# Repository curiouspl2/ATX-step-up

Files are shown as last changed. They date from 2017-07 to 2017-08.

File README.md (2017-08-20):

# ATX-step-up
DC DC step up driver turning flaky and sagging ATX power supply to stable 14V or 24V source

One can also use it to 'parallel' power supplies - just connect each power supply to separate input. 

v3 version supports four inputs, rated 10-20A each (depends on heatsinking and mosfets used).

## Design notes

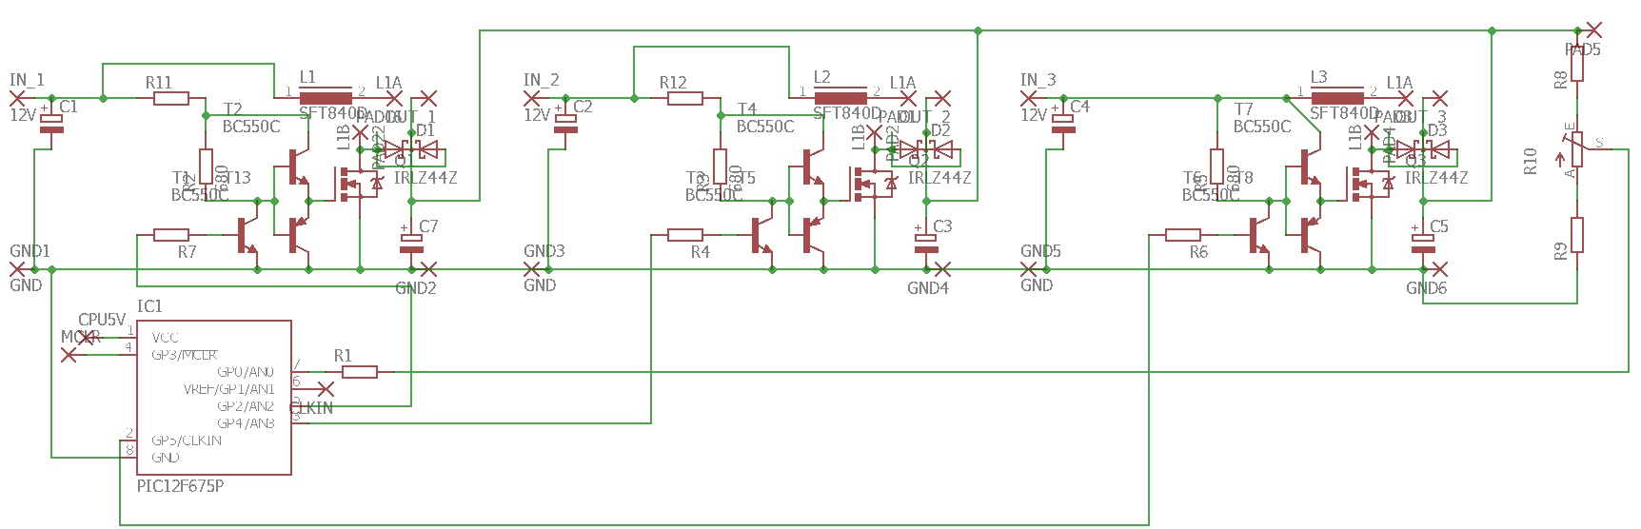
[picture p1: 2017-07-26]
pic_single_module_v1.png

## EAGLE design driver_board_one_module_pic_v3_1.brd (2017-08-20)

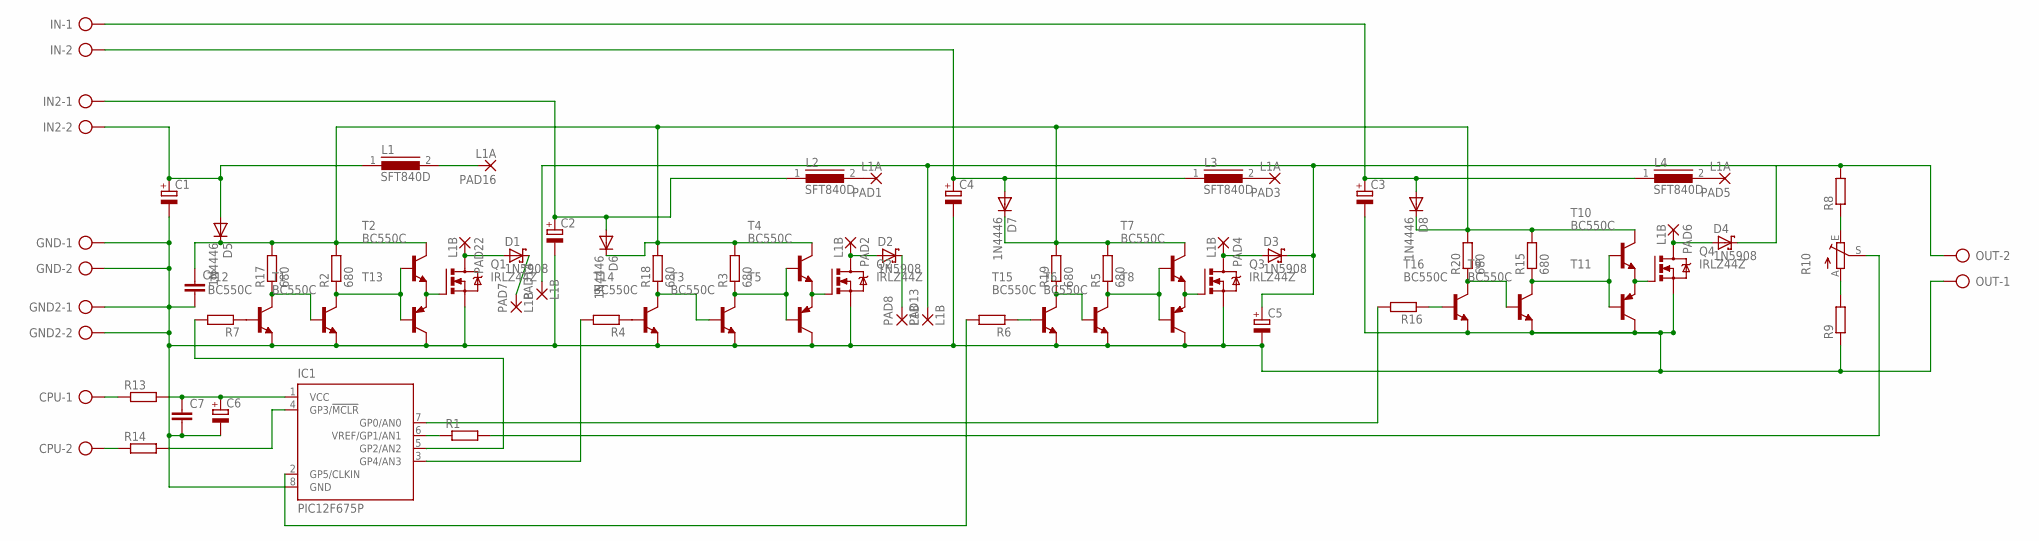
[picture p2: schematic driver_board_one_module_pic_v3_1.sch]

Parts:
C1, C2, C3, C4, C5, C6: CPOL-EUE5-8.5; E5-8,5
C7: C-EUC1206K; C1206K
C8: C-EU050-045X075; C050-045X075
CPU: AK300/2
D1, D2, D3, D4: 1N5908; C4111-15
D5, D6, D7, D8: 1N4446; DO35-10
GND, GND2: AK300/2
IC1: PIC12F675P; DIL8
IN, IN2: AK300/2
L1, L2, L3, L4: SFT840D
OUT: AK300/2
PAD1, PAD3, PAD5, PAD16: L1A; 3,81/1,1
PAD2, PAD4, PAD6, PAD7, PAD8, PAD13, PAD14, PAD22: L1B; 3,81/1,1
Q1, Q2, Q3, Q4: IRLZ44Z; TO220BH
R1, R8, R9, R13, R14: R-EU_0204/5; 0204/5
R2: 680; 0207/7
R3, R5, R15, R17, R18, R19, R20: 680; 0204/5
R4: R-EU_0207/7; 0207/7
R6, R7: R-EU_0207/12; 0207/12
R10: TRIM_EU-RJ9W; RJ9W
R16: R-EU_0207/10; 0207/10
T1, T2, T3, T4, T6, T7, T9, T10, T12, T14, T15, T16: BC550C; TO92-EBC
T5, T8, T11, T13: BC557C-PNP-TO92-EBC; TO92-EBC

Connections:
GND: C1.-, C2.-, C3.-, C4.-, C5.-, C6.-, C7.2, C8.2, GND.1, GND.2, GND2.1, GND2.2, IC1.8 (GND), OUT.1, Q1.S, Q2.S, Q3.S, Q4.S, R9.1, T1.E, T3.E, T5.C, T6.E, T8.C, T9.E, T11.C, T12.E, T13.C, T14.E, T15.E, T16.E
unnamed: Q1.G, T2.E, T13.E
unnamed: IC1.7 (GP0/AN0), R16.2
unnamed: Q2.G, T4.E, T5.E
unnamed: CPU.1, R13.1
unnamed: R9.2, R10.A
unnamed: R6.1, T15.B
unnamed: CPU.2, R14.1
unnamed: D2.A, PAD2.1, Q2.D
unnamed: R8.1, R10.E
unnamed: L2.2, PAD1.1
unnamed: Q3.G, T7.E, T8.E
unnamed: Q4.G, T10.E, T11.E
unnamed: R7.1, T12.B
unnamed: R1.2, R10.S
unnamed: R17.1, T1.B, T12.C
unnamed: D3.A, PAD4.1, Q3.D
unnamed: R4.1, T14.B
unnamed: R18.1, T3.B, T14.C
unnamed: L3.2, PAD3.1
unnamed: IC1.5 (GP2/AN2), R7.2
unnamed: IC1.3 (GP4/AN3), R4.2
unnamed: IC1.2 (GP5/CLKIN), R6.2
unnamed: C6.+, C7.1, IC1.1 (VCC), R13.2
unnamed: IC1.4 (GP3/!MCLR), R14.2
unnamed: IC1.6 (VREF/GP1/AN1), R1.1
unnamed: C1.+, D5.A, IN2.2, L1.1
unnamed: C2.+, D6.A, IN2.1, L2.1
unnamed: C4.+, D7.A, IN.2, L3.1
unnamed: D1.C, PAD7.1
unnamed: R16.1, T16.B
unnamed: L1.2, PAD16.1
unnamed: D1.A, PAD22.1, Q1.D
unnamed: R2.1, T1.C, T2.B, T13.B
unnamed: D4.A, PAD6.1, Q4.D
unnamed: L4.2, PAD5.1
unnamed: R3.1, T3.C, T4.B, T5.B
unnamed: C3.+, D8.A, IN.1, L4.1
unnamed: R5.1, T6.C, T7.B, T8.B
unnamed: R15.1, T9.C, T10.B, T11.B
unnamed: R19.1, T6.B, T15.C
unnamed: R20.1, T9.B, T16.C
unnamed: D2.C, PAD8.1
unnamed: C8.1, D5.C, D6.C, D7.C, D8.C, R2.2, R3.2, R5.2, R15.2, R17.2, R18.2, R19.2, R20.2, T2.C, T4.C, T7.C, T10.C
unnamed: C5.+, D3.C, D4.C, OUT.2, PAD13.1, PAD14.1, R8.2

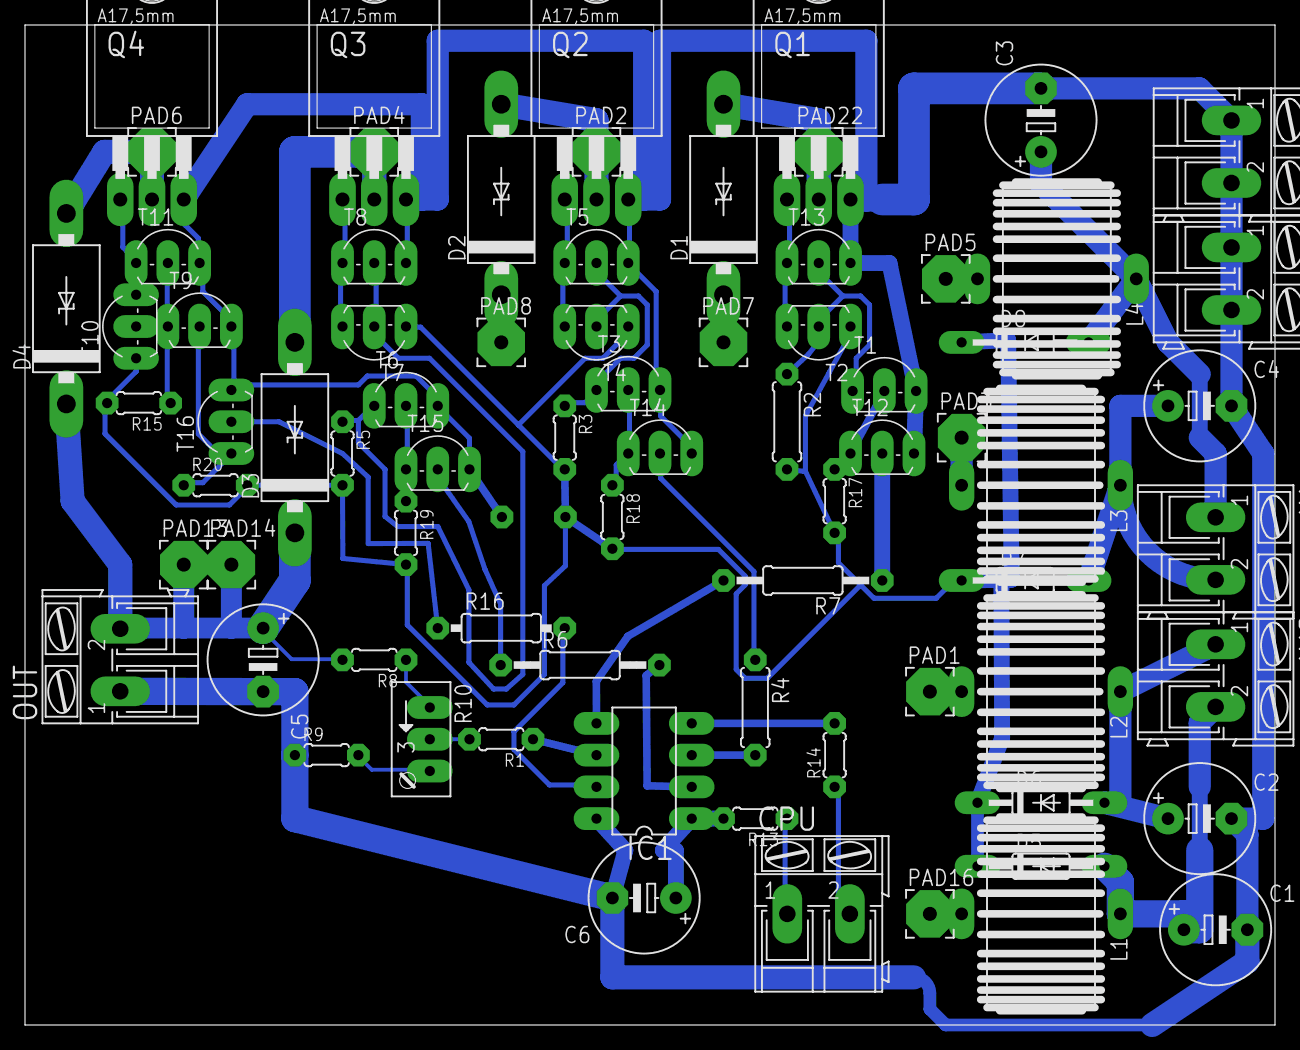
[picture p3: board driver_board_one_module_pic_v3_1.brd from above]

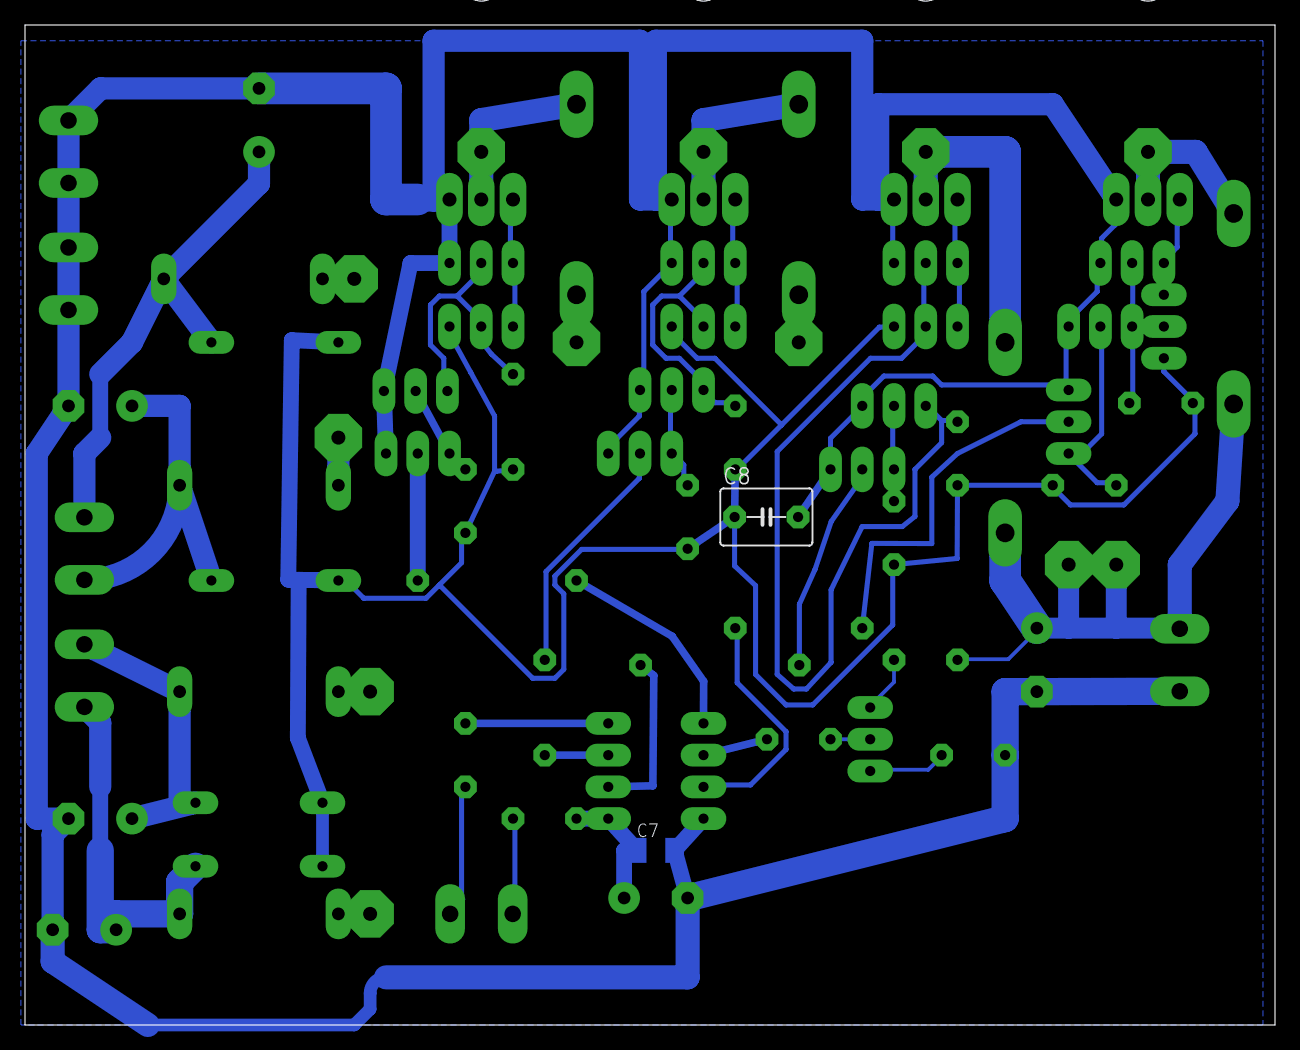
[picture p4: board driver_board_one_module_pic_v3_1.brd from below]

Board: 2 copper layers, 100.0 x 80.0 mm, 77 parts (2 on the bottom side), 45 nets.

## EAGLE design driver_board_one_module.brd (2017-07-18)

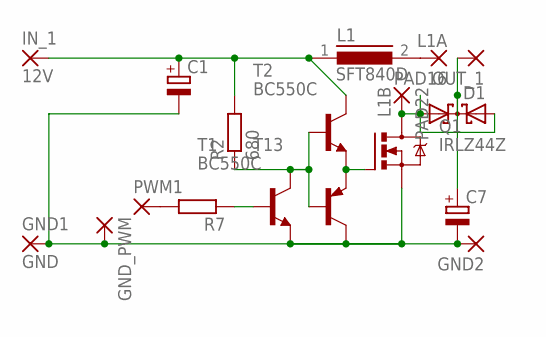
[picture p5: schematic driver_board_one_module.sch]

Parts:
C1, C7: CPOL-EUE5-8.5; E5-8,5
D1: DIODE_2SCHOTTKY-SOT93V; SOT93S
GND1: GND; 3,81/1,3
GND2: 3,81/1,3
GND_PWM: 2,54/0,8
IN_1: 12V; 3,81/1,3
L1: SFT840D
OUT_1: 3,81/1,3
PAD16: L1A; 3,81/1,1
PAD22: L1B; 3,81/1,1
PWM1: 2,54/0,8
Q1: IRLZ44Z; TO220BH
R2: 680; 0204/7
R7: R-EU_0207/7; 0207/7
T1, T2: BC550C; TO92-EBC
T13: BC557C-PNP-TO92-EBC; TO92-EBC

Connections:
unnamed: Q1.G, T2.E, T13.E
unnamed: R2.1, T1.C, T2.B, T13.B
unnamed: C1.-, C7.-, GND1.1, GND2.1, GND_PWM.1, Q1.S, T1.E, T13.C
unnamed: PWM1.1, R7.2
unnamed: R7.1, T1.B
unnamed: C1.+, IN_1.1, L1.1, R2.2, T2.C
unnamed: L1.2, PAD16.1
unnamed: D1.A1, D1.A2, PAD22.1, Q1.D
unnamed: C7.+, D1.C, OUT_1.1

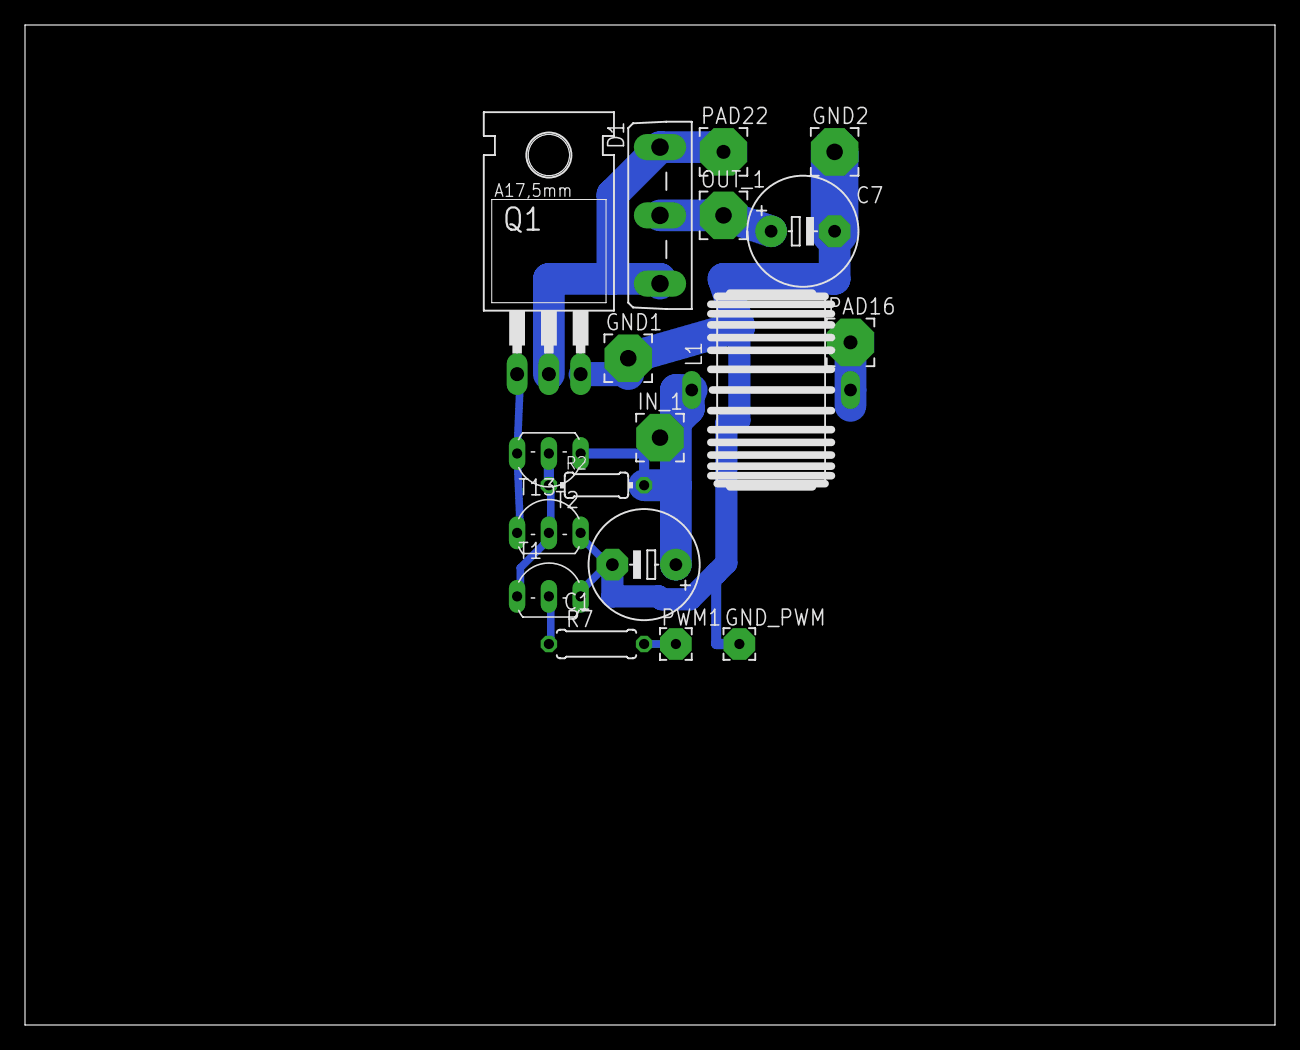
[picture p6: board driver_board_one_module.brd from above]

Board: 2 copper layers, 100.0 x 80.0 mm, 18 parts (0 on the bottom side), 9 nets.

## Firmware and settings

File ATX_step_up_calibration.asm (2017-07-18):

; this is dc-dc step up module cooperating with cheap ATX power supply.
 
; this code is cut down code allowing calibration of hardware. 
; it simply displays voltage readout from ADC, and threshold levels.
; one simply sets upper float voltage threshold level using voltage divider potentiometer
; and then one sets ADC scale potentiometer to make it display proper ADC value. 

;
;       CPU configuration
;

        MESSG           "Processor = 12F675"
        #define         RAMStart        0x20
        processor       12f675
        include         <p12f675.inc>

        __config        _INTRC_OSC_NOCLKOUT & _PWRTE_ON & _WDT_ON & _CP_OFF & _BODEN_ON  & _MCLRE_OFF
;       __config        _INTRC_OSC_NOCLKOUT & _PWRTE_ON & _WDT_OFF & _CP_OFF & _BODEN_ON  & _MCLRE_OFF

;*******************************************************************
;includes

	include 	"infrared_serial.asm"

; -----



bank0   macro
        errorlevel      +302            ; Re-enable bank warning
        bcf             STATUS,RP0      ; Select Bank 0
        endm

;-------------------------------------------------------------------
;       Select Register Bank 1

bank1   macro
        bsf             STATUS,RP0      ; Select Bank 1
        errorlevel      -302            ; disable warning
        endm


WDT_set_to_2s	macro			; sets WDT to 2 seconds. switches bank to bank0 
	bank1
        bsf     OPTION_REG,PS1
        nop
        bsf     OPTION_REG,PS2
        nop
        bsf     OPTION_REG,PS0  ; prescaler set to ~2s of time
        nop
        bsf     OPTION_REG,PSA  ; prescaler assigned to WDT.
	bank0
		endm


compare_gp1_gp0		macro	; turn on comparator, compare gp1 (inverting) and gp0 (noninverting)
        movlw   b'00000010'     ;  Comparator on, without output, comparing AN0 and AN1
        movwf   CMCON           ;
		endm

compare_gp1_CVref	macro
        movlw   b'00000100'     ;  Comparator on, without output, comparing AN1 and vref
        movwf   CMCON           ;  (we want to check battery state)
		endm

comparator_off	macro
        movlw   b'00000111'     ;  Comparator off, without output, inputs shorted to ground
        movwf   CMCON           ;  (conserve power)
		endm



if_comparator_set	macro
        btfsc   CMCON,COUT      ; if rectifier voltage is lower than battery, skip
	endm


#define		COMPARATOR_INVERTING_INPUT_TRIS		TRISIO,GP1
#define		COMPARATOR_NONINVERTING_INPUT_TRIS	TRISIO,GP0
#define		COMPARATOR_INVERTING_INPUT		GPIO,GP1
#define		COMPARATOR_NONINVERTING_INPUT		GPIO,GP0

#define		CHARGING_KEY_TRIS			TRISIO,GP5
#define		CHARGING_KEY				GPIO,GP5

#define		BATTERY_LOAD_KEY_TRIS			TRISIO,GP2
#define		BATTERY_LOAD_KEY			GPIO,GP2

#define		LED_IR_TRIS				TRISIO,GP4
#define		LED_IR					GPIO,GP4

#define		KEYBOARD_TRIS				TRISIO,GP3
#define		KEYBOARD				GPIO,GP3




;*******************************************************************

        cblock  RAMStart

	DELAY			; used by "CONVERT" subroutine
	bcd:8                   ; BCD, MSD first
        COUNT                   ; Bin to BCD convert (bit count)
        cnt                     ;                    (BCD BYTES)


        CHR
        TEMP                    ; DATS/Putchr temporary
        AccA:4                  ; Binary, MSByte first

        D_hex                   ; used by hex output routine
                                ; used by serial out routines
        S_Wtemp
        S_count
    	d1
    	d2
        S_mask                  ; used by IR routine
	COMPARATOR_LOW_RESULT	; internal comparator based ADC result low range
	COMPARATOR_HIGH_RESULT 	; internal comparator based ADC result high range
        endc



		org 0            ; Reset Vector
		goto INIT

		org 4            ; Interrupt Vector
		goto COMP
		org 5

INIT:		
		WDT_set_to_2s		; set WDT to time out after 2s and switch to bank0 

		clrwdt			; immediatelly clean it. 
		

;		movlw H'14'      ; 
		movlw b'00000100'      ; Timer 1:
					; 0 - TMR1ON - 0(off)
					; 1 - TMR1CS - 0(off) 
					; 2 - /T1SYNC - 1(off)
					; 3 - T1OSCEN - 0(off)

					; 4 - T1CKPS0 - 0 
					; 5 - T1CKPS1 - 0 ; 1:1 prescaler
					; 6 - - 0 
					; 7 - - 0 

		movwf T1CON      ; A 1 MHz clock is used


		bsf INTCON,GIE   ; Enable Global Int
		bsf INTCON,PEIE  ; Unmask Peripheral Int

it_is_hot:
	        bank1
	        call    calibration_hot		; calibration value for hot environment (above 0C)
        	movwf   OSCCAL			; calibrate internal oscillator - required as we do serial out which is timing critical

quit_thermal_calibration:
        	bank0   

MAIN:		
		clrwdt
;		call 	short_sleep		; sleep for 2 seconds. 
						; this ensures supply voltage settles, as chip consumes minimum power.

		call 	CONVERT			; measure voltage of battery
		clrwdt
		call	DISPLAY_VOLTAGE		; display voltage
		clrwdt
		call 	CONVERT_COMPARATOR_LOW	; measure voltage of battery using internal reference voltage and comparator
		clrwdt
		call 	DISPLAY_COMPARISON_RESULT_LOW ; display voltage of battery measured using comparator. 

		clrwdt
		call 	CONVERT_COMPARATOR_HIGH	; measure voltage of battery using internal reference voltage and comparator
		clrwdt
		call 	DISPLAY_COMPARISON_RESULT_HIGH	 ; display voltage of battery measured using comparator. 

		call	crlf			; new line. 
		clrwdt
;	call 	long_sleep		; sleep for 2 seconds.
		goto MAIN





DISPLAY_COMPARISON_RESULT_LOW:
	clrf 	AccA
	clrf	AccA+1
	clrf	AccA+2
	movfw	COMPARATOR_LOW_RESULT
	movwf	AccA+3
	goto	display_5_digit_number

DISPLAY_COMPARISON_RESULT_HIGH:
	clrf 	AccA
	clrf	AccA+1
	clrf	AccA+2
	movfw	COMPARATOR_HIGH_RESULT
	movwf	AccA+3
	goto	display_5_digit_number



;-------------------- simply dumps TMR1H and TMR1L value to console
DISPLAY_VOLTAGE:
        clrf    AccA
        clrf    AccA+1
        movfw 	TMR1H
        movwf   AccA+2
        movfw   TMR1L
        movwf   AccA+3

display_5_digit_number:		; this is common subroutine to display 5 digit (16bit decimal) number. 

;       Format as BCD string
;        iorwf   FPE,f           ; W may hold Error (0xff)

        call    B2_BCD          ; format as BCD
                                ; extract and send to display


        MOVF    bcd+5,W         ; 5  
        CALL    PutNyb

        SWAPF   bcd+6,W         ; 4  
        CALL    PutNyb

	movlw	"."
	call	putchr		; . 


        MOVF    bcd+6,W         ; 3  
        CALL    PutNyb

        SWAPF   bcd+7,W         ; 2  
        CALL    PutNyb

        MOVF    bcd+7,W         ; 1  
        CALL    PutNyb

	movlw	" "
	call	putchr		; " " space after each number 

	return

		


;-------------------------16bit ADC subroutine

CONVERT:	
		bank0
		compare_gp1_gp0		; turn on comparator, compare gp1 (inverting) and gp0 (noninverting)
		clrf 	TMR1L       ; Clear Timer 1 L
		clrf 	TMR1H       ; Clear Timer 1 H

		bank1
		bsf	COMPARATOR_INVERTING_INPUT_TRIS  ; set GP0 as input
		bcf 	PIR1,TMR1IF
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
